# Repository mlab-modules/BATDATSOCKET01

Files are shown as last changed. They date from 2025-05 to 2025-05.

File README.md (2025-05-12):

# BATDATSOCKET01 - Li-ion power and Data Storage Module socket interface

The BATDATSOCKET01 is a complementary module to the battery and data module [BATDATUNIT01](https://github.com/mlab-modules/BATDATUNIT01). It is a reliable power source for extended durations, making it an integral component in a wide array of detectors or measuring systems.

## Applications

The BATDATUNIT01 is designed for versatility:

- As a **power module for semiconductor particle detectors** like the [AIRDOS04](https://github.com/UniversalScientificTechnologies/AIRDOS04), it ensures uninterrupted data acquisition in environmental monitoring.
- It can be integrated into **remote sensing stations**, providing consistent power and data logging capabilities for long-term ecological studies.
- In **automated weather stations**, the module's resilience and sensor suite offer valuable insights into meteorological conditions.
- The module can be deployed in **mobile robotics** for energy supply and environmental data collection, aiding navigation and decision-making processes.
- It is also ideal for **educational purposes**, as a hands-on tool to teach about energy management, data acquisition, and sensor integration.

For more detailed information on interfacing and protocols, please refer to the [BATDATUNIT01](https://github.com/mlab-modules/BATDATUNIT01) documentation.

## Design

Designed for convenience, the module allows for fast detachment from the measuring part without tools, streamlining the replacement process. Data can be downloaded during battery charging thanks to onboard memory.

BATDATSOCKET01 top view

BATDATSOCKET01 bottom view

### Internal structure

```mermaid

    flowchart TD

    subgraph a[User interfaceI]
        USB[[USB-C\nData + power]]
        UI1([User interface \n Button + battery indicator])
        UI2([User interface \n Button + 3x LED])
    
    end

    USB --USB --> USW

    FTDI -- I2C --> I2CSW
    FTDI -- UART <--> MCU
    MCU -- I2C --> I2CSW[I2C mux]
    MCU[Microcontroller]
    MCU --SPI <--> SDW
    MCU --> SDW

    subgraph one[Memory interface]
    SDR[SD card] <--> SDI
    SDI[SD card interface] <--> USW
    USW[USB-SWITCH]
    SDW[SD card \n SPI-SWITCH] <--> SDI
    end

    subgraph three[Digital part ]
    USW -- USB <--> FTDI[FTDI\nI2C + UART]

    I2CSW --I2C--> HYG[Hygrometer]
    I2CSW --I2C--> ALT[Pressure sensor]

    I2CSW -- I2C --> I2Cen

    end

    I2CSW --I2C--> GAUGE
    I2CSW --I2C--> charger

    GAUGE --> UI1
    MCU --> UI2

    GAUGE --> PWR3v3
    GAUGE --> PWR3v3E
    GAUGE --> PWR5vE
    
    USW -- USB <--> FTDI[FTDI\nI2C + UART]
    USB -- Power --> charger

    subgraph two[POWER sources]
    PWR3v3[Power supply\nfor internal 3.3V]
    PWR3v3E[Power supply\nfor detector 3.3V]
    PWR5vE[Power supply\nfor detector 5V]
    
    charger --> GAUGE[Accumulators gauge]
    GAUGE <==> LIION[(5x Li-ion cells)]
    end
    PWR3v3 --> MCU

    PWR3v3E --> DI
    PWR5vE --> DI

    I2Cen[I2C switch] -- I2C --> DI
    DI[[Detector interface]] == GPIO, SPI <==> MCU

```

## Connectivity

A durable connector brings together data and detection elements with impressive mechanical resilience. It hosts UART, I2C, SPI buses, and extra GPIO signals, providing extensive interfacing options with various systems.

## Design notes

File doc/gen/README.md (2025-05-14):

# PCB

Board size: 23.61x85.85 mm (0.93x3.38 inches)

- This is the size of the rectangle that contains the board
- Thickness: 1.6 mm (63 mils)
- Material: FR4
- Finish: None
- Layers: 2
- Copper thickness: 35 µm

Solder mask: TOP / BOTTOM

- Color: White

Silk screen: TOP / BOTTOM

- Color: Black

Stackup:

| Name | Type | Color | Thickness [µm]| Material | Er | Loss tan |
|---|---|---|---|---|---|---|
| F.SilkS | Top Silk Screen | Black | | | | |
| F.Paste | Top Solder Paste | | | | | |
| F.Mask | Top Solder Mask | White | 10 | | | |
| F.Cu | copper | | 35 | | | |
| dielectric 1 | core | FR4 natural | 1510 | FR4 | 4.5 | 0.020 |
| B.Cu | copper | | 35 | | | |
| B.Mask | Bottom Solder Mask | White | 10 | | | |
| B.Paste | Bottom Solder Paste  | | | | | |
| B.SilkS | Bottom Silk Screen | Black | | | | |

# Important sizes

Clearance: 0.2 mm (8 mils)

Track width: 0.25 mm (10 mils)

- By design rules: 0.0 mm (0 mils)

Drill: 0.5 mm (20 mils)

- Vias: 0.5 mm (20 mils) [Design: 0.4 mm (16 mils)]
- Pads: 0.85 mm (33 mils)
- The above values are real drill sizes, they add 0.1 mm (4 mils) to plated holes (PTH)

Via: 0.8/0.4 mm (31/16 mils)

- By design rules: 0.5/0.3 mm (20/12 mils)
- Micro via: yes [0.2/0.1 mm (8/4 mils)]
- Buried/blind via: yes
- Total: 3 (thru: 3 buried/blind: 0 micro: 0)

Outer Annular Ring: 0.15 mm (6 mils)

- By design rules: 0.23 mm (9 mils)

Eurocircuits class: 4B
- Using min drill 0.5 mm for an OAR of 0.15 mm

# General stats

Components count: (SMD/THT)

- Top: 4/5 (SMD + THT)
- Bottom: 0/2 (THT)

Defined tracks:

Used tracks:

- 0.25 mm (10 mils) (15) defined: no
- 0.3 mm (12 mils) (74) defined: no
- 0.4 mm (16 mils) (5) defined: no
- 0.5 mm (20 mils) (52) defined: no
- 3.0 mm (118 mils) (3) defined: no

Defined vias:

Used vias:

- 0.8/0.4 mm (31/16 mils) (Count: 3, Aspect: 2.0 A) defined: no

Holes (excluding vias):

- 0.75 mm (30 mils) (30)
- 0.89 mm (35 mils) (6)
- 1.0 mm (39 mils) (30)
- 1.02 mm (40 mils) (40)
- 3.0 mm (118 mils) (4)
- 3.2 mm (126 mils) (2)

Oval holes:

Drill tools (including vias and computing adjusts and rounding):

- 0.5 mm (20 mils) (3)
- 0.85 mm (33 mils) (30)
- 1.0 mm (39 mils) (6)
- 1.1 mm (43 mils) (70)
- 3.0 mm (118 mils) (2)
- 3.1 mm (122 mils) (2)
- 3.2 mm (126 mils) (2)

Solder paste stats:

Using a paste with 87.75 % alloy, that has an specific gravity for the alloy of 7.4 g/cm³
and 1.0 g/cm³ for the flux. This paste has an specific gravity of  4.15 g/cm³.

The stencil thickness is  0.12 mm.

| Side | Pads with paste | Area [mm²] | Paste [g] |
|---|---|---|---|
| Total  | 8 | 10.74 | 0.05 |

Note: this is just an approximation to the theoretical value. Margins of the solder mask and waste aren't computed.

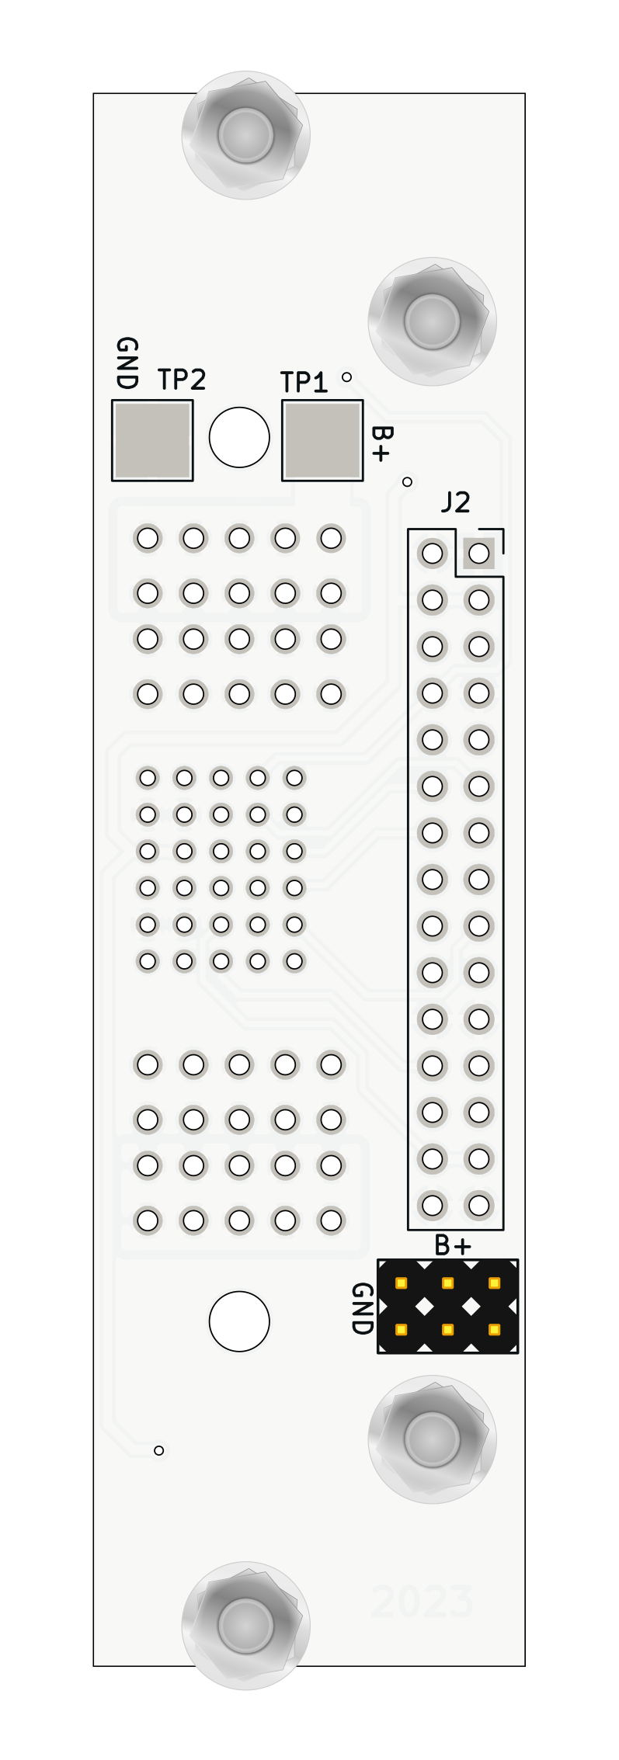
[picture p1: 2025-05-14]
doc/gen/img/BATDATSOCKET01-bottom.png

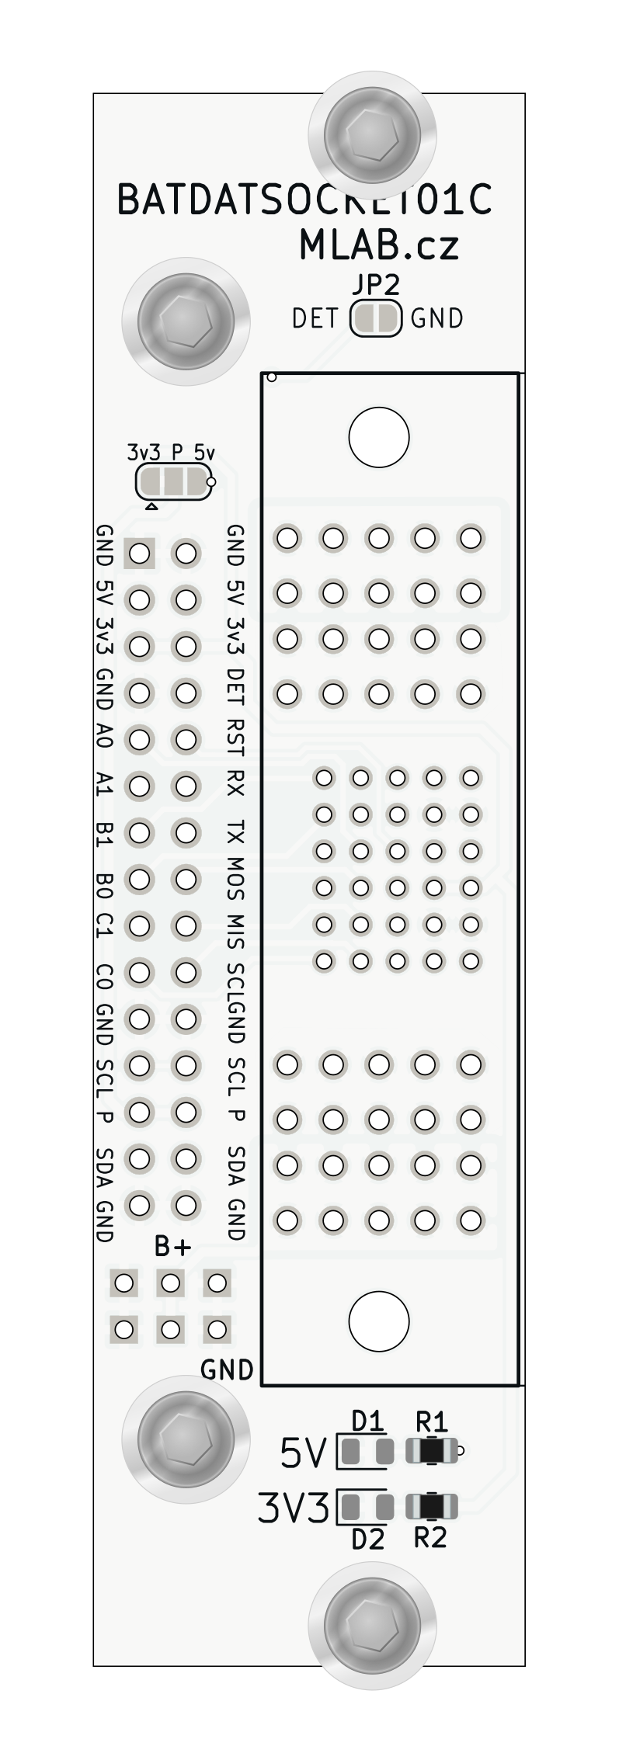
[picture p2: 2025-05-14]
doc/gen/img/BATDATSOCKET01-top.png

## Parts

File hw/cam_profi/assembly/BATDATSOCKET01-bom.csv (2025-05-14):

Component | Description | Part | References | Value | Footprint | Quantity Per PCB | Datasheet | ust_id
1 | Light emitting diode | LED | D1D2 | LED 0805 | LED_0805_2012Metric | 2 | ~
2 |  | MOLEX_46436-9327 | J1 | 46436-9327 | MOLEX_46437-9327 | 1 |  | 65481dfa462c6d9e72056b22
3 | 2x03 2.54 mm pitch header, 2 pins next to each other are connected | HEADER_2x03_PARALLEL | J3 | HEADER_2x03_PARALLEL | Straight_2x03 | 1
4 | 2x15 2.54 mm pitch header | HEADER_2x15 | J2 | HEADER_2x15 | PinSocket_2x15_P2.54mm_Vertical | 1 |  | 68226dbfee7fc534862c67d1
5 | Jumper, 2-pole, open | Jumper_2_Open | JP2 | Jumper_2_Open | SolderJumper-2_P1.3mm_Open_RoundedPad1.0x1.5mm | 1 | ~
6 | Jumper, 3-pole, pins 1+2 closed/bridged | Jumper_3_Bridged12 | JP1 | Jumper_3_Bridged12 | SolderJumper-3_P1.3mm_Bridged12_RoundedPad1.0x1.5mm | 1 | ~
7 | Resistor, small symbol | R_Small | R1R2 | 270R | R_0805_2012Metric | 2 | ~

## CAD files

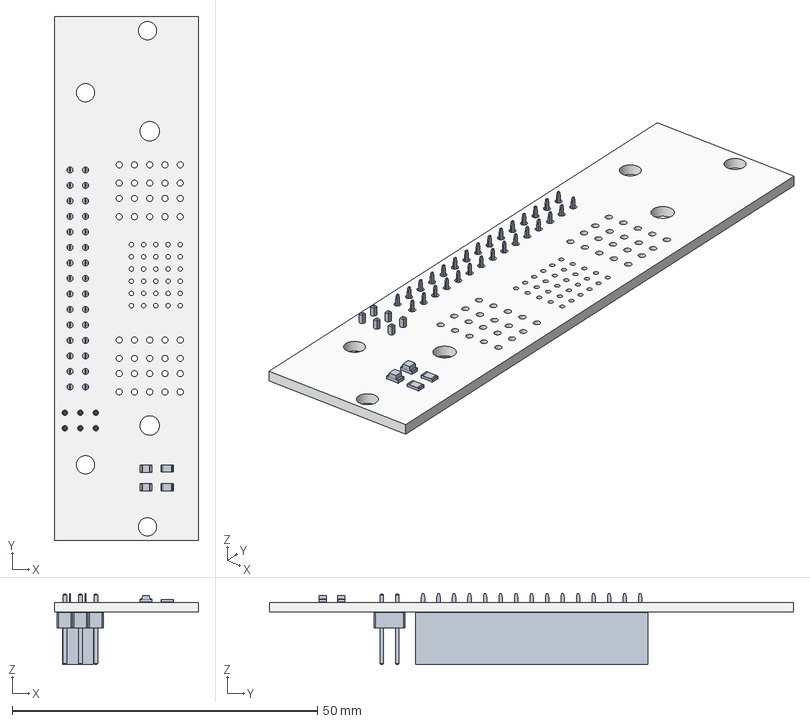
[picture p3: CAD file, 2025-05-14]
doc/gen/BATDATSOCKET01.step
23.6 x 85.9 x 11.6 mm
R_0805_2012Metric x 2
LED_0805_2012Metric x 2
PinHeader_2x03_P2.54mm_Vertical
PinSocket_2x15_P2.54mm_Vertical
kibot_yfogvzr5_PCB

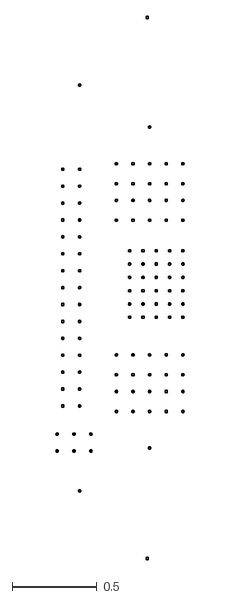
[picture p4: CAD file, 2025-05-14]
doc/gen/dxf/BATDATSOCKET01-User_8.dxf
0.758 x 3.21

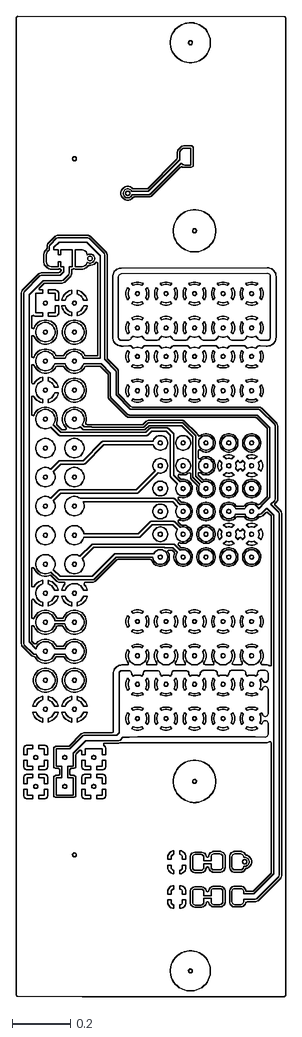
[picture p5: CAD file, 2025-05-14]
doc/gen/dxf/BATDATSOCKET01-F_Cu.dxf
0.929 x 3.38

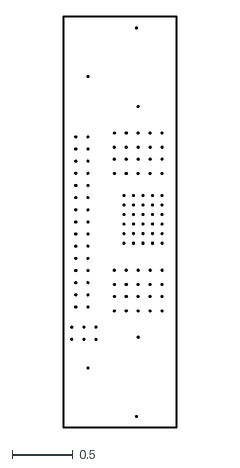
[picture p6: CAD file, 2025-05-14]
doc/gen/dxf/BATDATSOCKET01-Edge_Cuts.dxf
0.934 x 3.38

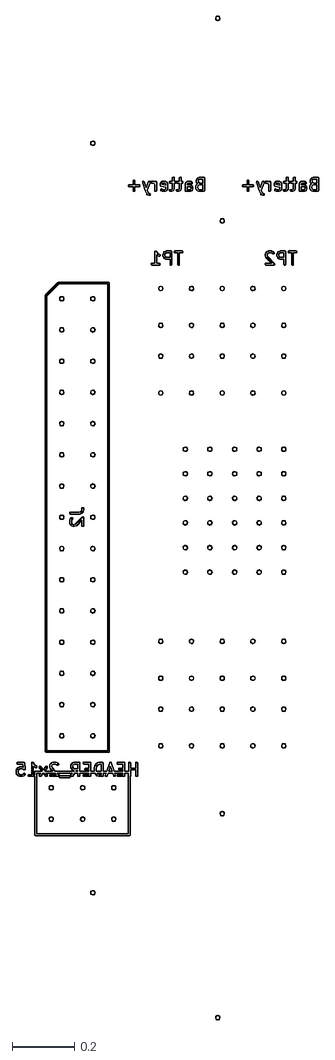
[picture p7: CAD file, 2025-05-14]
doc/gen/dxf/BATDATSOCKET01-B_Fab.dxf
0.968 x 3.21

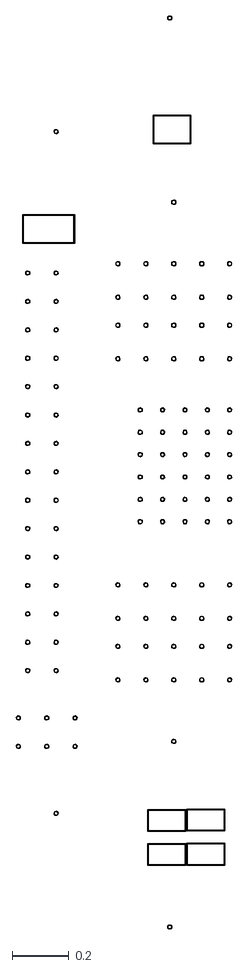
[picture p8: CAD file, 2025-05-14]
doc/gen/dxf/BATDATSOCKET01-F_Courtyard.dxf
0.758 x 3.21

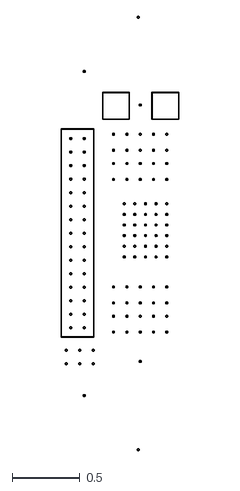
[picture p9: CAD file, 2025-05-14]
doc/gen/dxf/BATDATSOCKET01-B_Courtyard.dxf
0.87 x 3.21

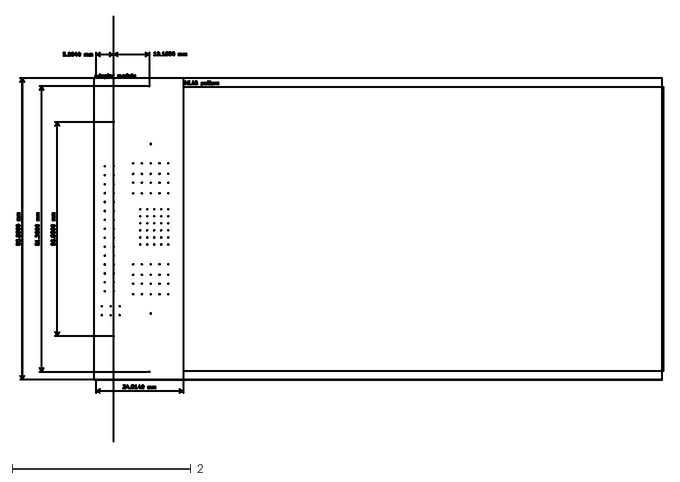
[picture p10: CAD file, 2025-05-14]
doc/gen/dxf/BATDATSOCKET01-User_Drawings.dxf
7.26 x 4.77

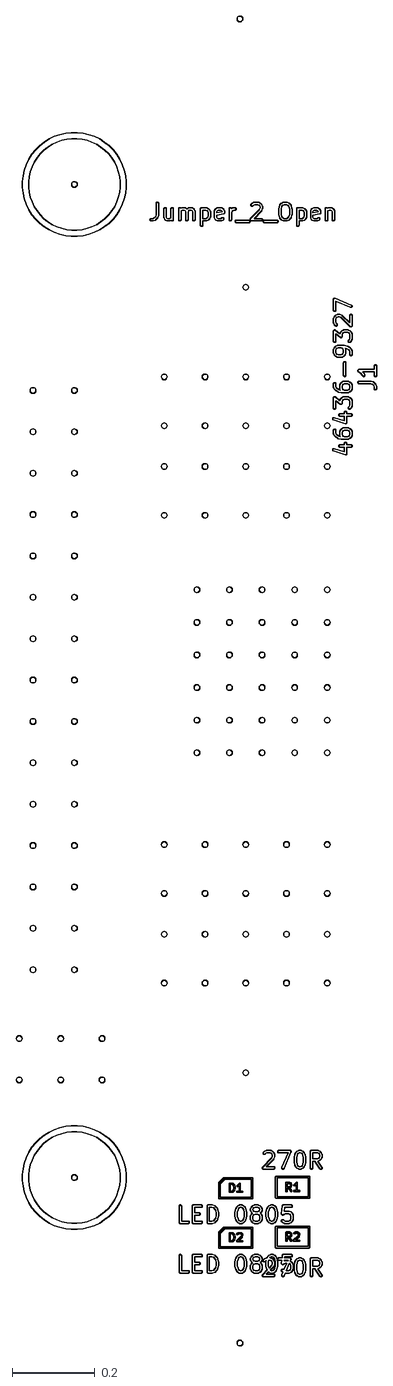
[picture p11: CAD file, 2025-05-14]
doc/gen/dxf/BATDATSOCKET01-F_Fab.dxf
0.87 x 3.21

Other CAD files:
doc/gen/dxf/BATDATSOCKET01-B_Adhesive.dxf
doc/gen/dxf/BATDATSOCKET01-B_Cu.dxf
doc/gen/dxf/BATDATSOCKET01-B_Mask.dxf
doc/gen/dxf/BATDATSOCKET01-B_Paste.dxf
doc/gen/dxf/BATDATSOCKET01-B_Silkscreen.dxf
doc/gen/dxf/BATDATSOCKET01-F_Adhesive.dxf
doc/gen/dxf/BATDATSOCKET01-F_Mask.dxf
doc/gen/dxf/BATDATSOCKET01-F_Paste.dxf
doc/gen/dxf/BATDATSOCKET01-F_Silkscreen.dxf
doc/gen/dxf/BATDATSOCKET01-User_Eco1.dxf

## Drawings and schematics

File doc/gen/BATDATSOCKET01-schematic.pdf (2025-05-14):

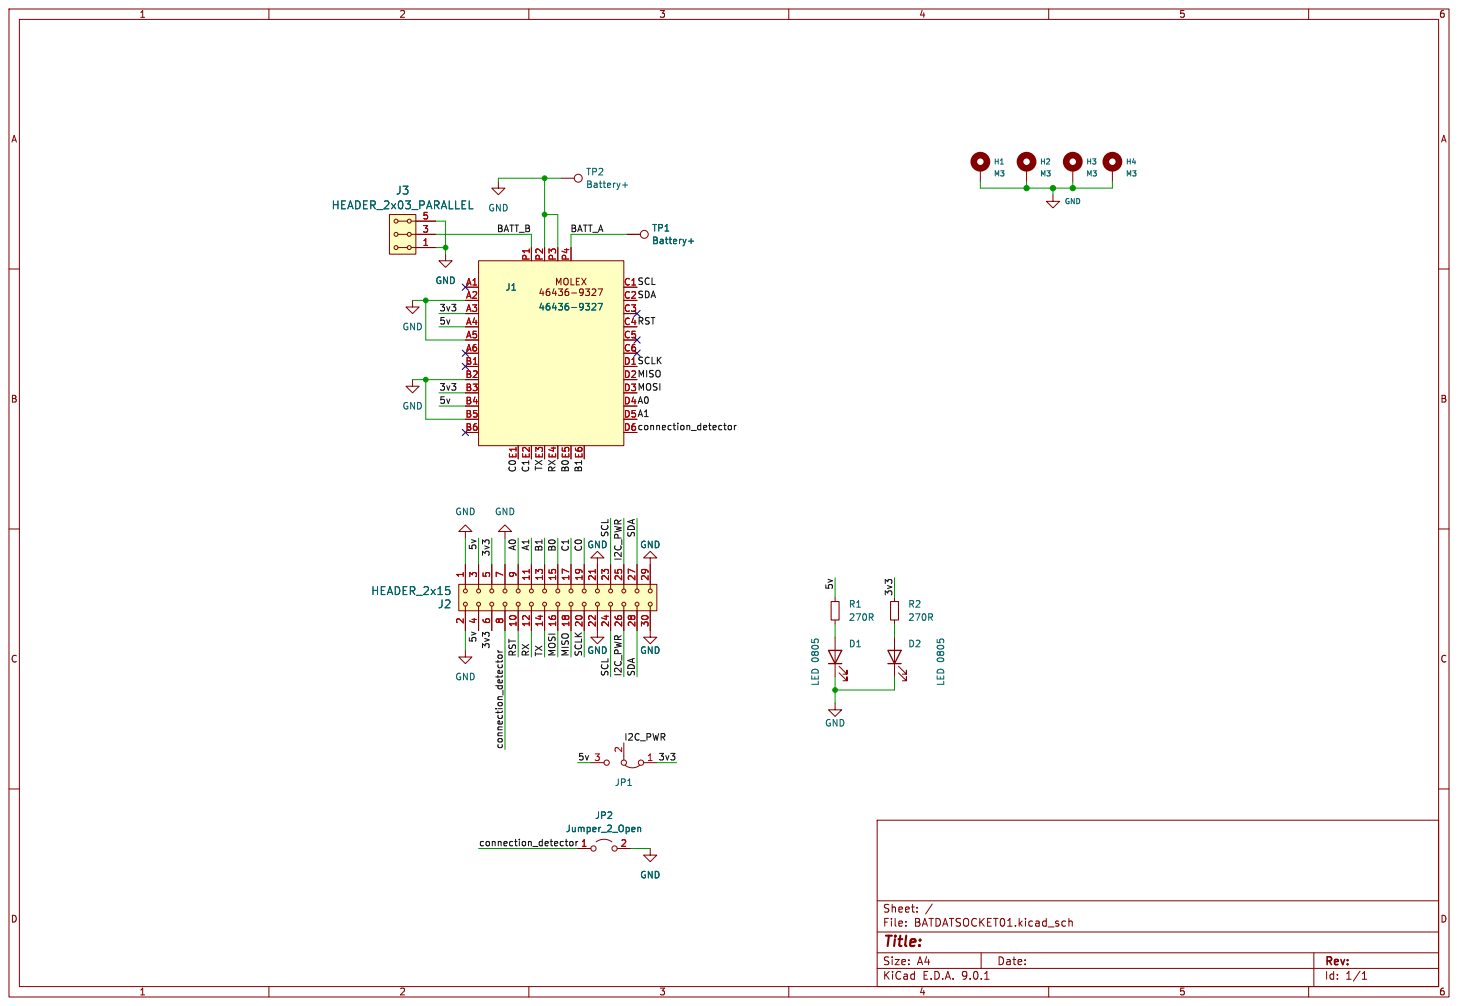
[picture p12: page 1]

Id: 1/1 Title: File: BATDATSOCKET01.kicad_sch Sheet: / GND

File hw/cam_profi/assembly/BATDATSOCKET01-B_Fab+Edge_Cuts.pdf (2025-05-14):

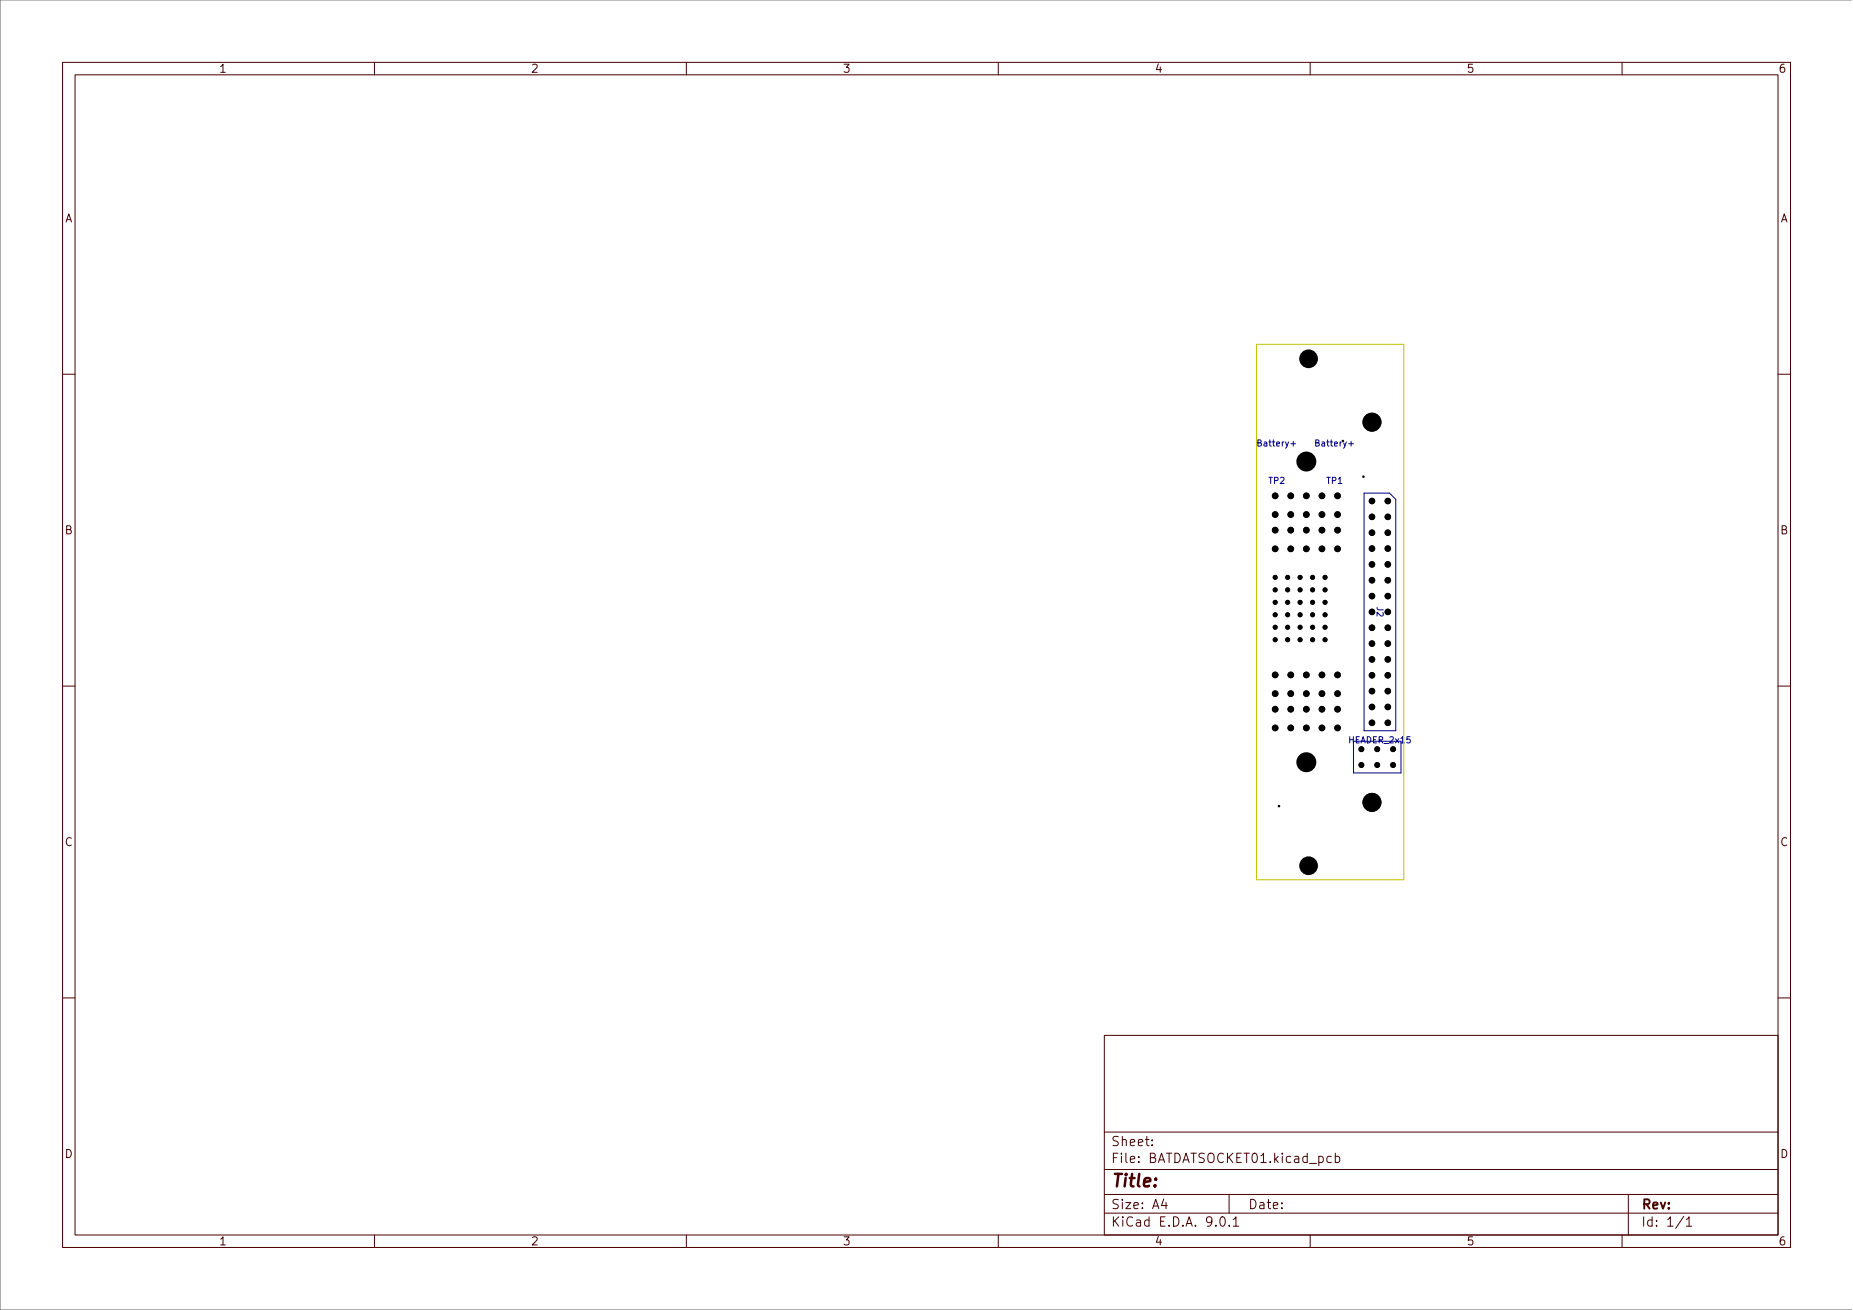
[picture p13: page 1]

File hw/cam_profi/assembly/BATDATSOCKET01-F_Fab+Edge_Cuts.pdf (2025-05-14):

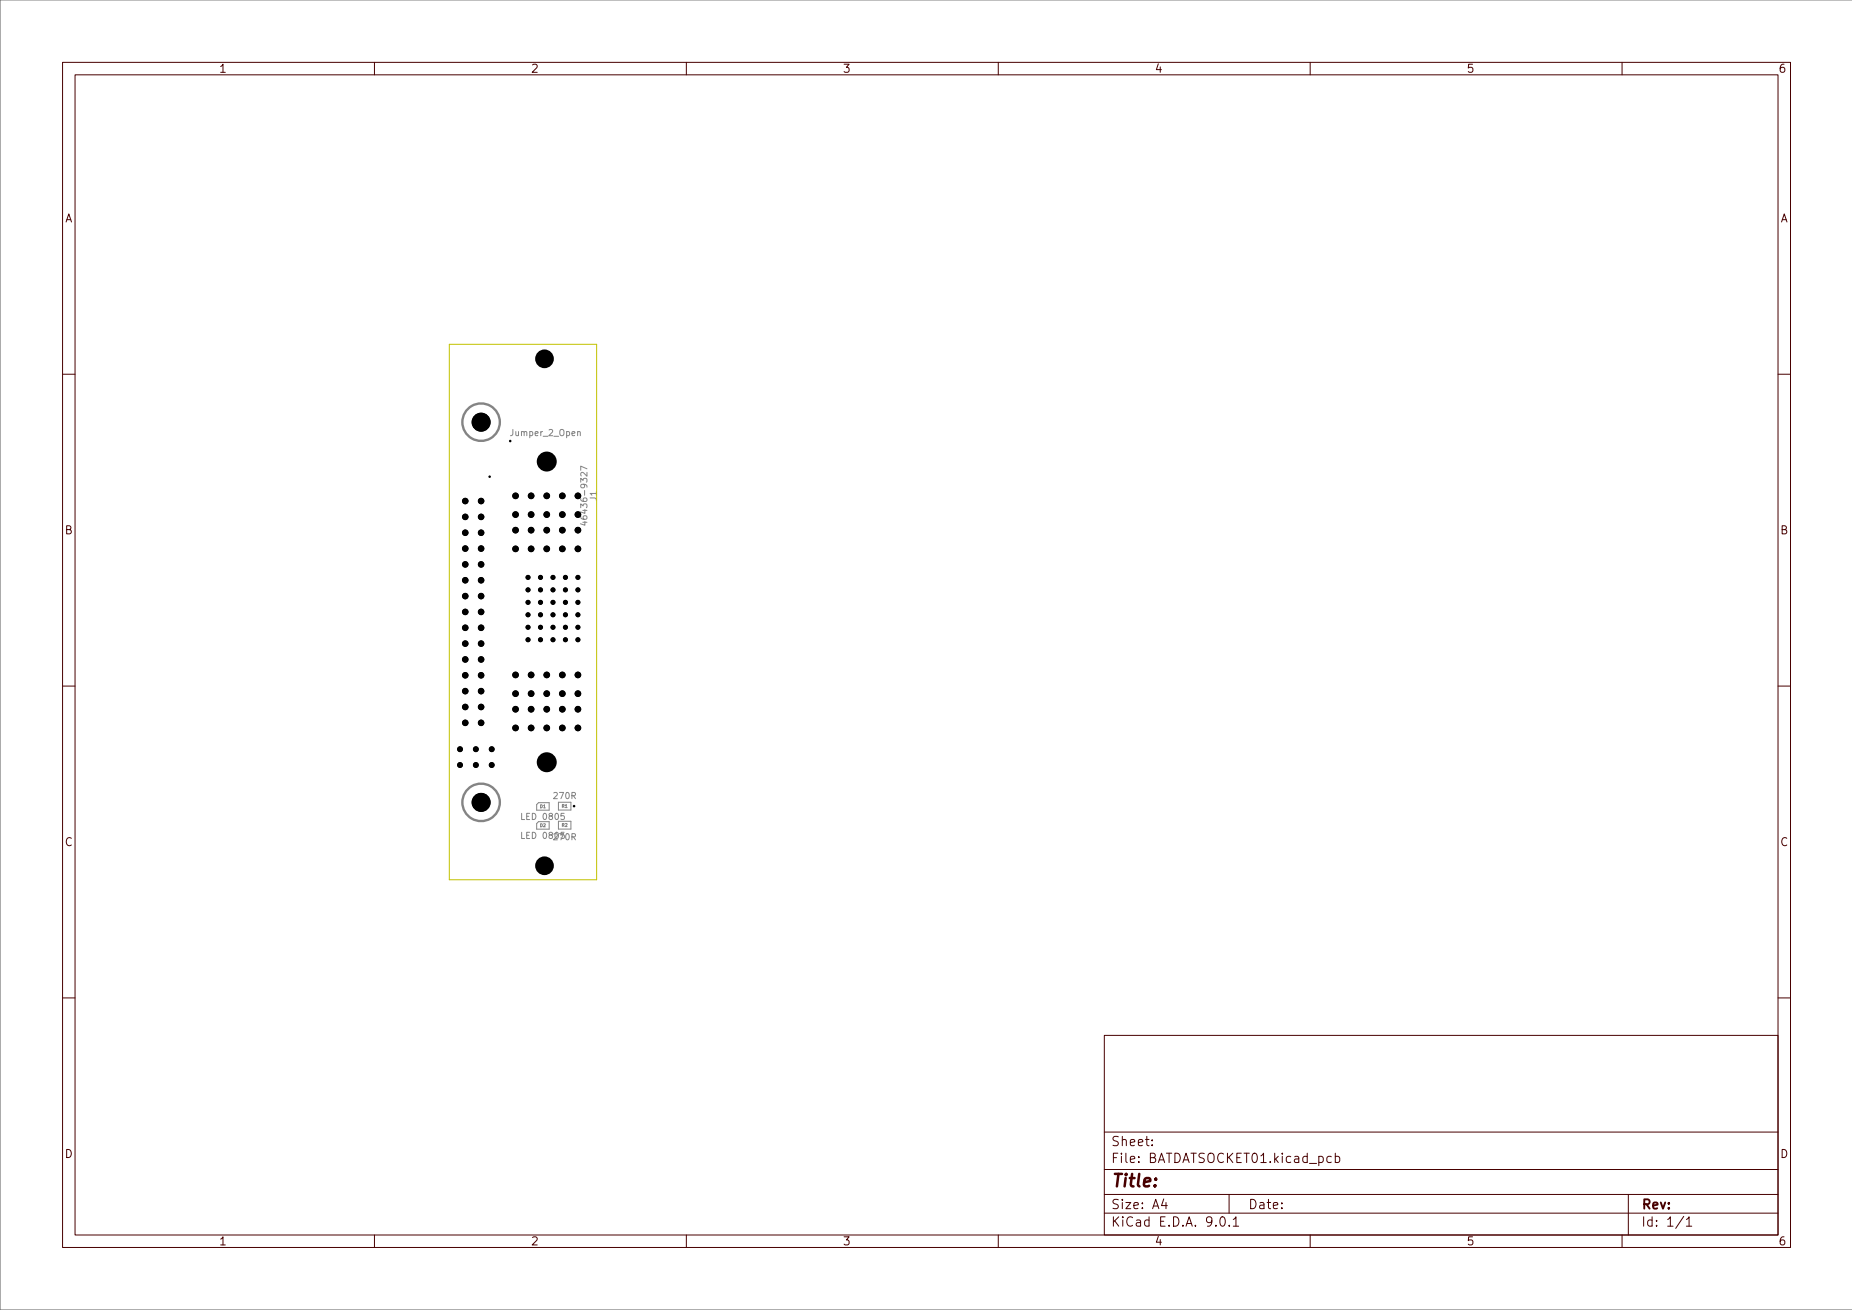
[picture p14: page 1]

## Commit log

2023-11-04 split from BATDATUNIT01A
    [BATDATSOCKET01.kicad_pcb, BATDATSOCKET01.kicad_sch]
2023-11-06 Improve layout, add det jumper
    [BATDATSOCKET01.kicad_pcb, BATDATSOCKET01.kicad_sch]
2023-11-06 Update actions products
    [BATDATSOCKET01-B_Adhesive.dxf, BATDATSOCKET01-B_Courtyard.dxf, BATDATSOCKET01-B_Cu.dxf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]
2023-11-07 Revised schematics.
    [BATDATSOCKET01.kicad_sch]
2023-11-07 bigger spacing around BATT+ pins
    [BATDATSOCKET01.kicad_pcb]
2023-11-23 add reset pin
    [BATDATSOCKET01.kicad_pcb, BATDATSOCKET01.kicad_sch]
2023-11-27 Pinheader changed to pin-socket.
    [BATDATSOCKET01.kicad_pcb, BATDATSOCKET01.kicad_sch]
2025-05-11 Fix UST_ID for molex connector.
    [BATDATSOCKET01.kicad_sch]
2025-05-12 Update connector UST_ID.
    [BATDATSOCKET01.kicad_pcb, BATDATSOCKET01.kicad_sch]
2025-05-12 Update workflows to KiCADv8.
2025-05-14 Resolve #1
    [BATDATSOCKET01.kicad_pcb, BATDATSOCKET01.kicad_sch]
2025-05-14 Update submodule to KiCADv9 branch.
2026-01-20 Update title block.
    [BATDATSOCKET01.kicad_sch]
